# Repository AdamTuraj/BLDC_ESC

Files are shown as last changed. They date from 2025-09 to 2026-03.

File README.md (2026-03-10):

# BLDC ESC

**25A 8.4V Sensored BLDC Motor Driver (DRV8323 Based)**

This ESC was originally designed for my **AT25 project**, but the project was discontinued due to time and budget constraints. The board itself is theoretically still fully functional (I have not physically tested it).

- **Continuous Current:** 25A
- **Peak Current:** 50A
- **Input Voltage:** 8.4V (2S Li-Po)
- **Driver IC:** TI DRV8323
- **Control Mode:** Single PWM mode (simplifies control, avoids heavy math)

## Design Overview

The ESC is built around the **DRV8323** gate driver IC, making use of its 1x PWM control mode for easier firmware integration.

## Renders & Schematics

### 3D Renders

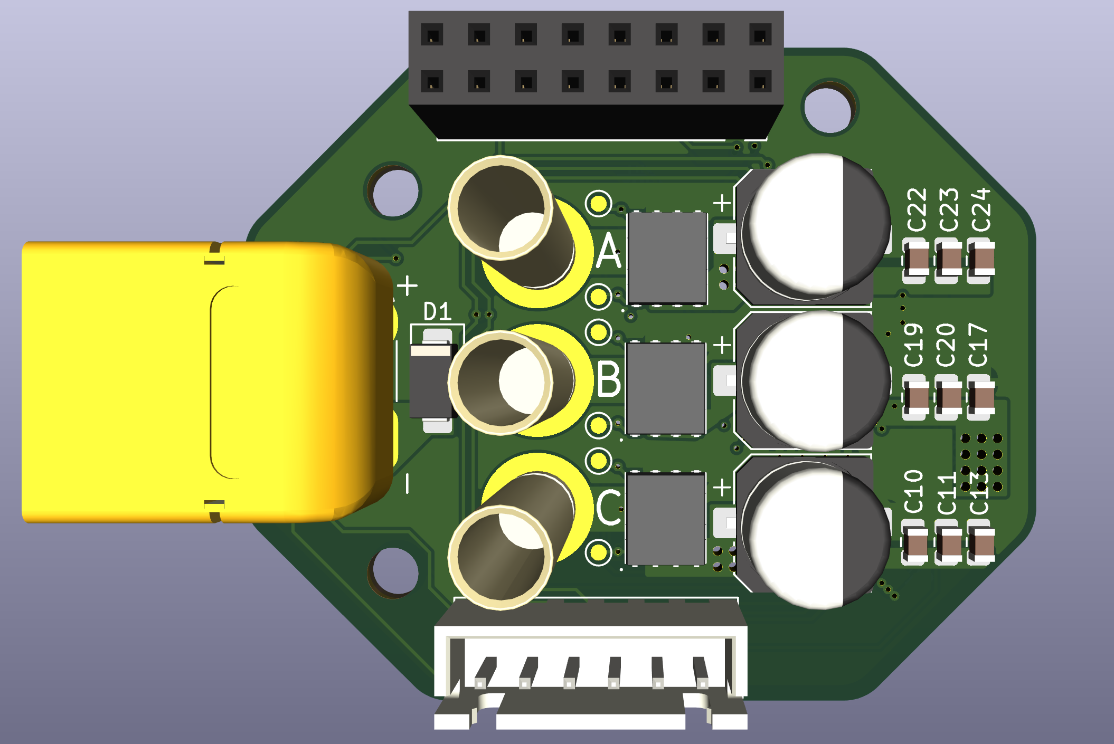
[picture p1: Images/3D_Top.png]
Top 3D view
  
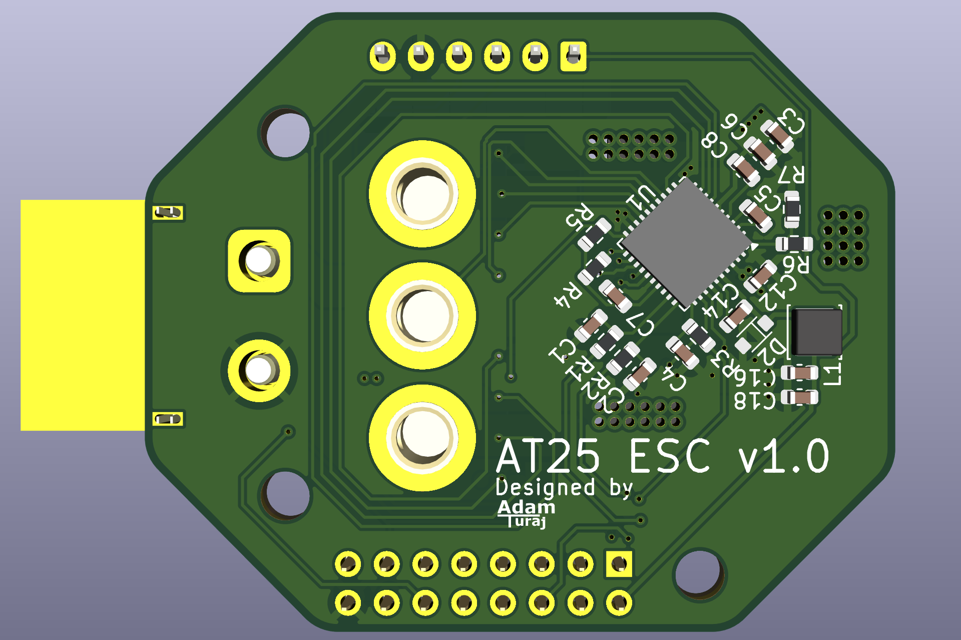
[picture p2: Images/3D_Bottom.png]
Bottom 3D view


### Electrical Schematic

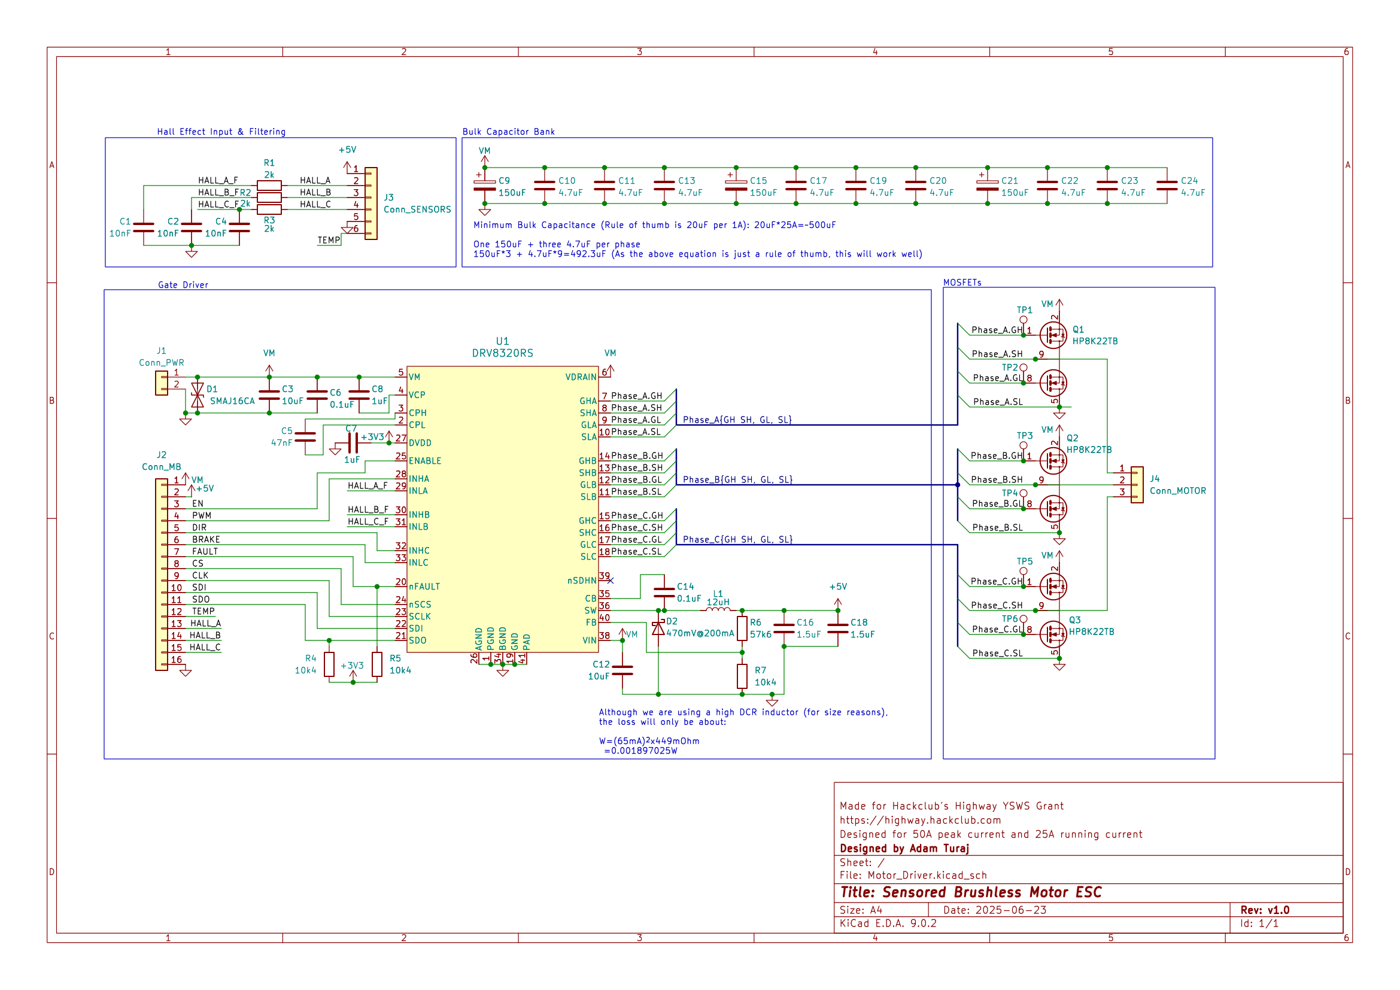
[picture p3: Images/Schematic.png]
Schematic


### PCB Layout (4-Layer Stackup)

- **Top Layer (Signals)**  
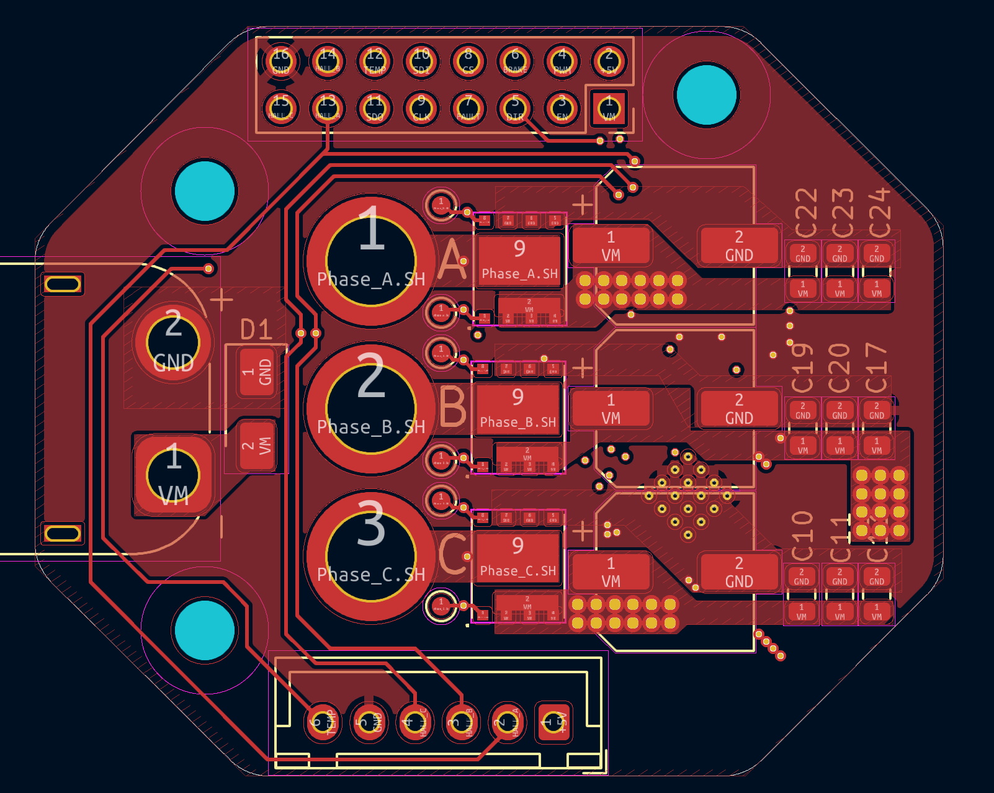
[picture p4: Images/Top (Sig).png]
Top Layer
  

- **Second Layer (Ground Plane)**  
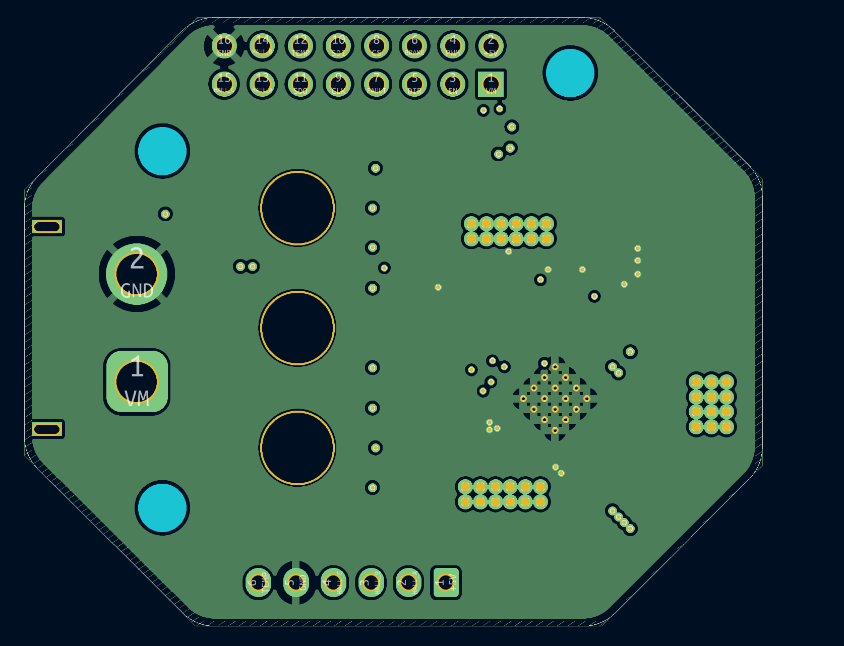
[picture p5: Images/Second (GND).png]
Second Layer
  

- **Third Layer (Power / Signals)**  
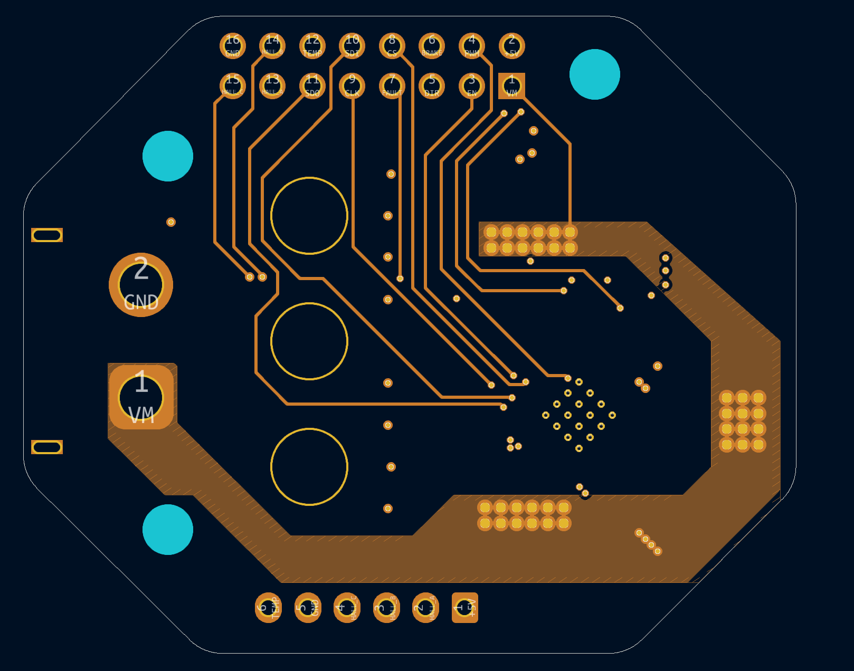
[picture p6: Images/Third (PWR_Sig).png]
Third Layer
  

- **Bottom Layer (Signals)**  
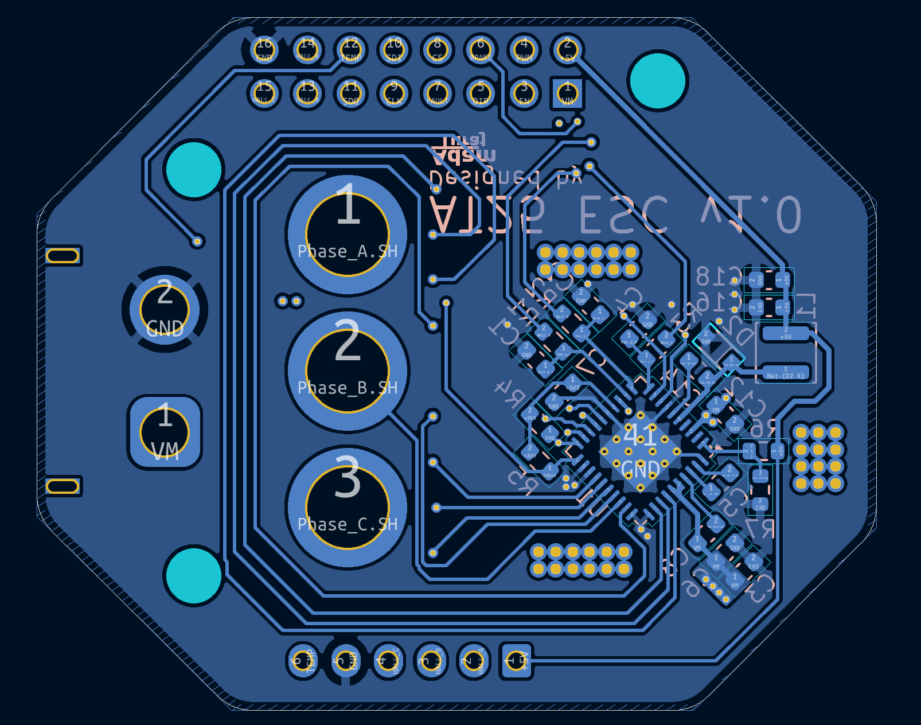
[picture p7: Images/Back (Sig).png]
Bottom Layer


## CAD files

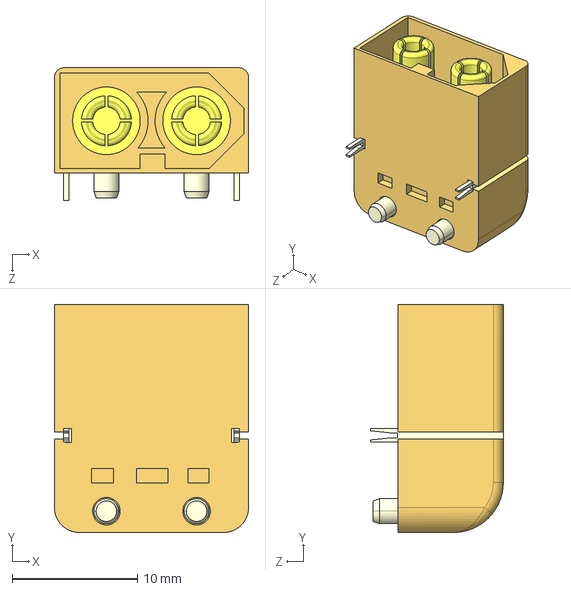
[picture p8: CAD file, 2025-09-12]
STEP/XT60PW-M.STEP
15.5 x 18.2 x 10.6 mm

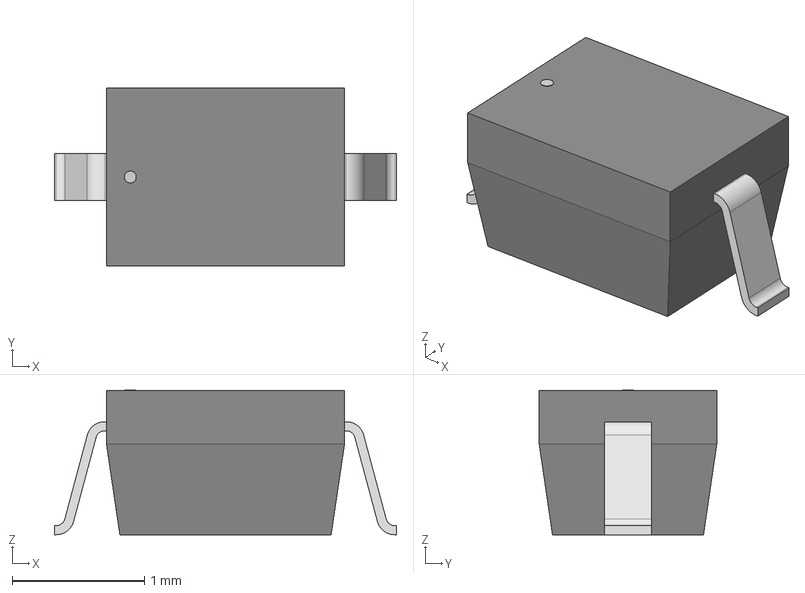
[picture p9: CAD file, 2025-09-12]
STEP/SOD-323_CNS.step
2.59 x 1.35 x 1.09 mm

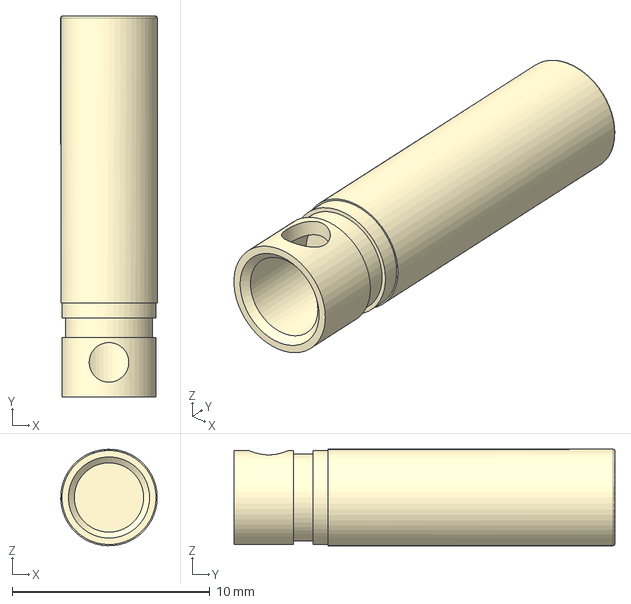
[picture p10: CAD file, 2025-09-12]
STEP/Female_4mm_Bullet_Connector.step
4.88 x 19.2 x 4.88 mm

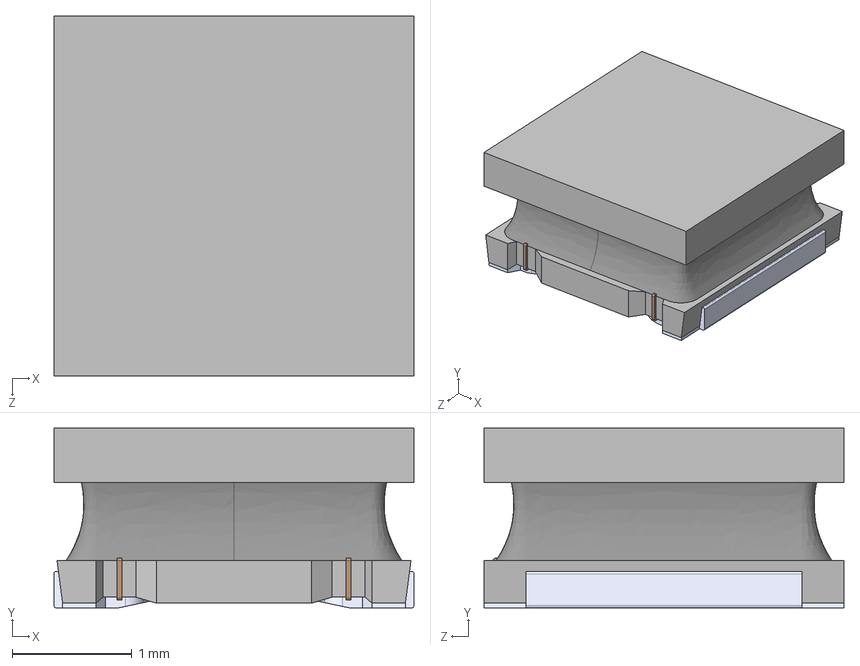
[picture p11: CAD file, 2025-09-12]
STEP/LQH3NPN6R8MMEL.STEP
3.00 x 1.50 x 3.00 mm

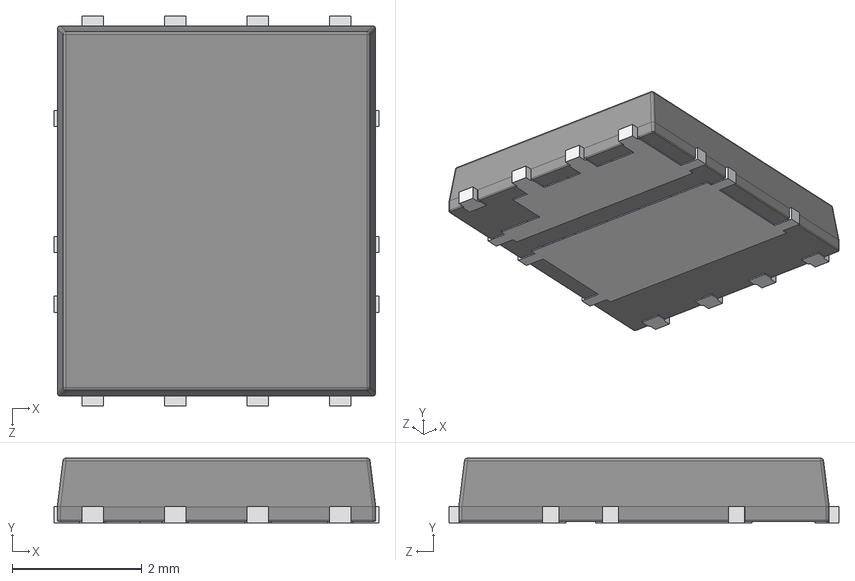
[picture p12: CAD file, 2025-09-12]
STEP/HP8K22TB.stp
5.00 x 1.00 x 6.00 mm

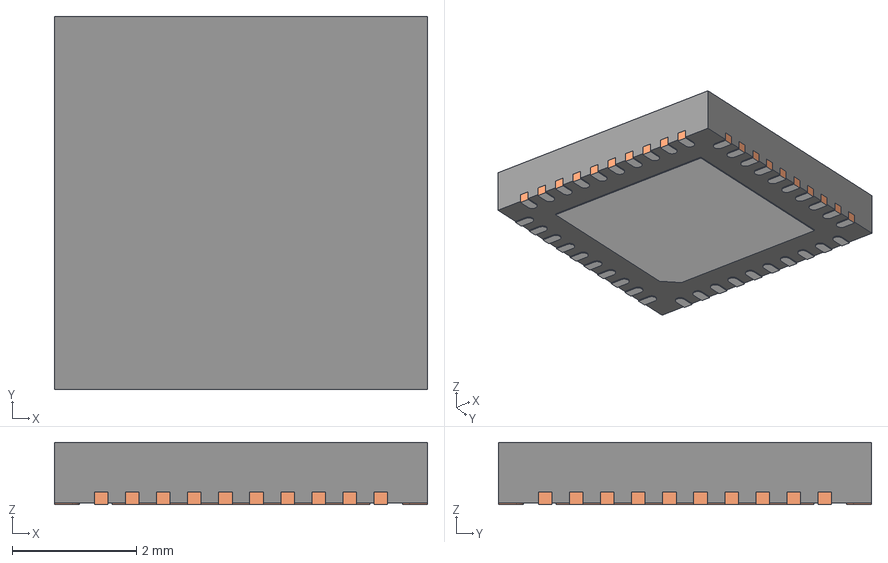
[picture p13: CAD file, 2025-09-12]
STEP/RHA0040B.stp
6.00 x 6.00 x 1.00 mm
BODY-QFN
FRAME-RHA0040B
PIN1-ID

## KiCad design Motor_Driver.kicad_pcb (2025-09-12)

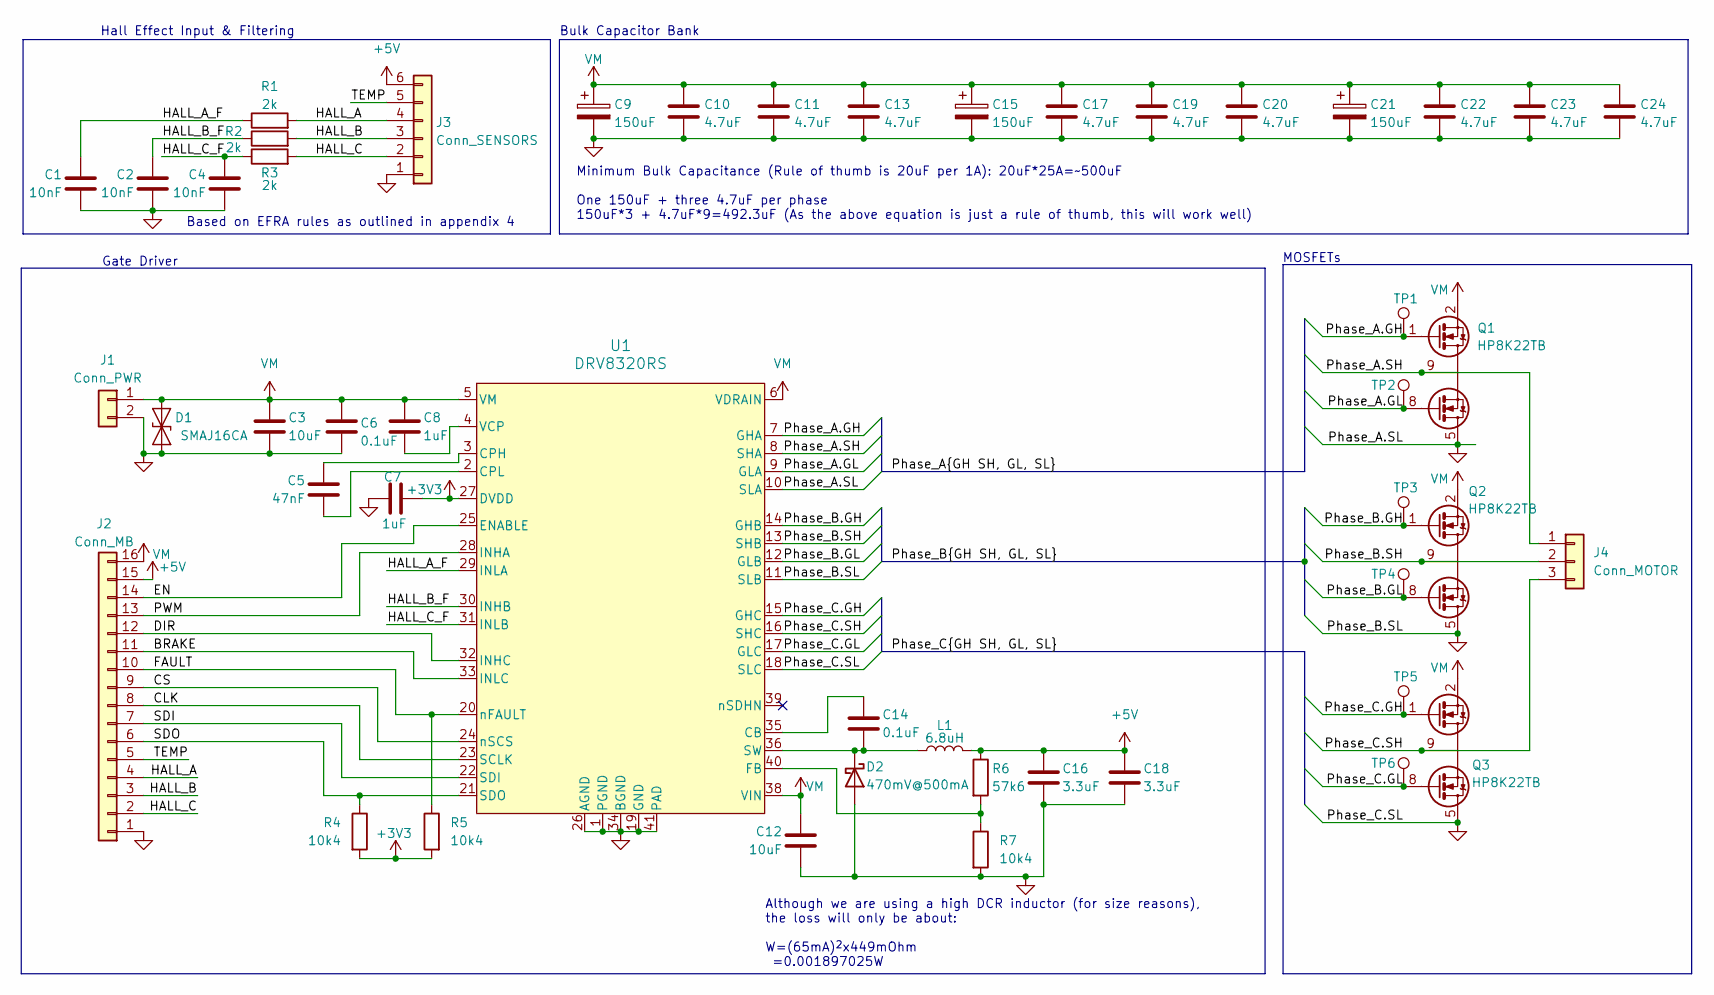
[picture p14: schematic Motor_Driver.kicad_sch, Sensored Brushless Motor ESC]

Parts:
C1, C2, C4: 10nF; C_0603_1608Metric; MPN CL10B103KO8WPNC
C3, C12: 10uF; C_0603_1608Metric; MPN GRM188C81C106MA73D
C5: 47nF; C_0603_1608Metric
C6, C14: 0.1uF; C_0603_1608Metric; MPN CC0603KRX7R7BB104
C7, C8: 1uF; C_0603_1608Metric; MPN CC0603KRX7R7BB105
C9, C15, C21: 150uF; CP_Elec_8x6.9; MPN APXN160ARA151MH70G
C10, C11, C13, C17, C19, C20, C22, C23, C24: 4.7uF; C_0805_2012Metric; MPN CL21B475KOFNNNE
C16, C18: 3.3uF; C_0603_1608Metric; MPN CL10A335KP8NNNC
D1: SMAJ16CA; D_SMA; MPN SMAJ16CA-13-F
D2: 470mV@500mA; D_SOD-323; MPN CMDSH05-4 TR PBFREE
J1: Conn_PWR; AMASS_XT60PW-M_1x02_P7.20mm_Horizontal
J2: Conn_MB; PinSocket_2x08_P2.54mm_Vertical; MPN 10129381-916001BLF
J3: Conn_SENSORS; JST_ZH_B6B-ZR_1x06_P1.50mm_Vertical; MPN B6B-XH-A
J4: Conn_MOTOR; Pin_Bullet_D4.7mm
L1: 6.8uH; L_Vishay_IHLP-1212; MPN LQH3NPN6R8MMEL
Q1, Q2, Q3: HP8K22TB; HP8K24TB; MPN HP8K22TB
R1, R2, R3: 2k; R_0603_1608Metric; MPN RK73B1JTTD202J
R4, R5, R7: 10k4; R_0603_1608Metric; MPN RT0603BRD0710K4L
R6: 57k6; R_0603_1608Metric; MPN RC0603FR-0757K6L
TP1, TP2, TP3, TP4, TP5, TP6: TestPoint; TestPoint_Pad_D1.0mm
U1: DRV8320RS; VQFN-40-1EP_6x6mm_P0.5mm_EP3.5x3.5mm_ThermalVias; MPN DRV8320RSRHAT

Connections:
+3V3: C7.1, R4.2, R5.2, U1.27 (DVDD)
+5V: C16.1, C18.1, J2.15, J3.6, L1.2, R6.1
/BRAKE: J2.11, U1.33 (INLC)
/CLK: J2.8, U1.23 (SCLK)
/CS: J2.9, U1.24 (nSCS)
/DIR: J2.12, U1.32 (INHC)
/EN: J2.14, U1.25 (ENABLE)
/FAULT: J2.10, R5.1, U1.20 (nFAULT)
/HALL_A: J2.4, J3.4, R1.2
/HALL_A_F: C1.1, R1.1, U1.29 (INLA)
/HALL_B: J2.3, J3.3, R2.2
/HALL_B_F: C2.1, R2.1, U1.30 (INHB)
/HALL_C: J2.2, J3.2, R3.2
/HALL_C_F: C4.1, R3.1, U1.31 (INLB)
/PWM: J2.13, U1.28 (INHA)
/Phase_A.GH: Q1.1 (T_{G}), TP1.1, U1.7 (GHA)
/Phase_A.GL: Q1.8 (B_{G}), TP2.1, U1.9 (GLA)
/Phase_A.SH: J4.1, Q1.9 (T_{GR}), U1.8 (SHA)
/Phase_B.GH: Q2.1 (T_{G}), TP3.1, U1.14 (GHB)
/Phase_B.GL: Q2.8 (B_{G}), TP4.1, U1.12 (GLB)
/Phase_B.SH: J4.2, Q2.9 (T_{GR}), U1.13 (SHB)
/Phase_C.GH: Q3.1 (T_{G}), TP5.1, U1.15 (GHC)
/Phase_C.GL: Q3.8 (B_{G}), TP6.1, U1.17 (GLC)
/Phase_C.SH: J4.3, Q3.9 (T_{GR}), U1.16 (SHC)
/SDI: J2.7, U1.22 (SDI)
/SDO: J2.6, R4.1, U1.21 (SDO)
/TEMP: J2.5, J3.5
GND: C1.2, C2.2, C3.2, C4.2, C6.2, C7.2, C9.2, C10.2, C11.2, C12.2, C13.2, C15.2, C16.2, C17.2, C18.2, C19.2, C20.2, C21.2, C22.2, C23.2, C24.2, D1.1 (A1), D2.2 (A), J1.2, J2.1, J3.1, Q1.5 (P_{GND}), Q1.6 (P_{GND}), Q1.7 (P_{GND}), Q2.5 (P_{GND}), Q2.6 (P_{GND}), Q2.7 (P_{GND}), Q3.5 (P_{GND}), Q3.6 (P_{GND}), Q3.7 (P_{GND}), R7.2, U1.1 (PGND), U1.10 (SLA), U1.11 (SLB), U1.18 (SLC), U1.19 (GND), U1.26 (AGND), U1.34 (BGND), U1.41 (PAD)
unnamed: C14.2, D2.1 (K), L1.1, U1.36 (SW)
unnamed: C14.1, U1.35 (CB)
unnamed: C5.1, U1.3 (CPH)
unnamed: C5.2, U1.2 (CPL)
unnamed: R6.2, R7.1, U1.40 (FB)
unnamed: C8.2, U1.4 (VCP)
VM: C3.1, C6.1, C8.1, C9.1, C10.1, C11.1, C12.1, C13.1, C15.1, C17.1, C19.1, C20.1, C21.1, C22.1, C23.1, C24.1, D1.2 (A2), J1.1, J2.16, Q1.2 (V_{IN}), Q1.3 (V_{IN}), Q1.4 (V_{IN}), Q2.2 (V_{IN}), Q2.3 (V_{IN}), Q2.4 (V_{IN}), Q3.2 (V_{IN}), Q3.3 (V_{IN}), Q3.4 (V_{IN}), U1.5 (VM), U1.6 (VDRAIN), U1.38 (VIN)

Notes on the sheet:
MOSFETs
Although we are using a high DCR inductor (for size reasons), the loss will only be about: W=(65mA)^{2}x449mOhm =0.001897025W
Hall Effect Input & Filtering
Based on EFRA rules as outlined in appendix 4
Gate Driver
Minimum Bulk Capacitance (Rule of thumb is 20uF per 1A): 20uF*25A=~500uF One 150uF + three 4.7uF per phase 150uF*3 + 4.7uF*9=492.3uF (As the above equation is just a rule of thumb, this will work well)
Bulk Capacitor Bank

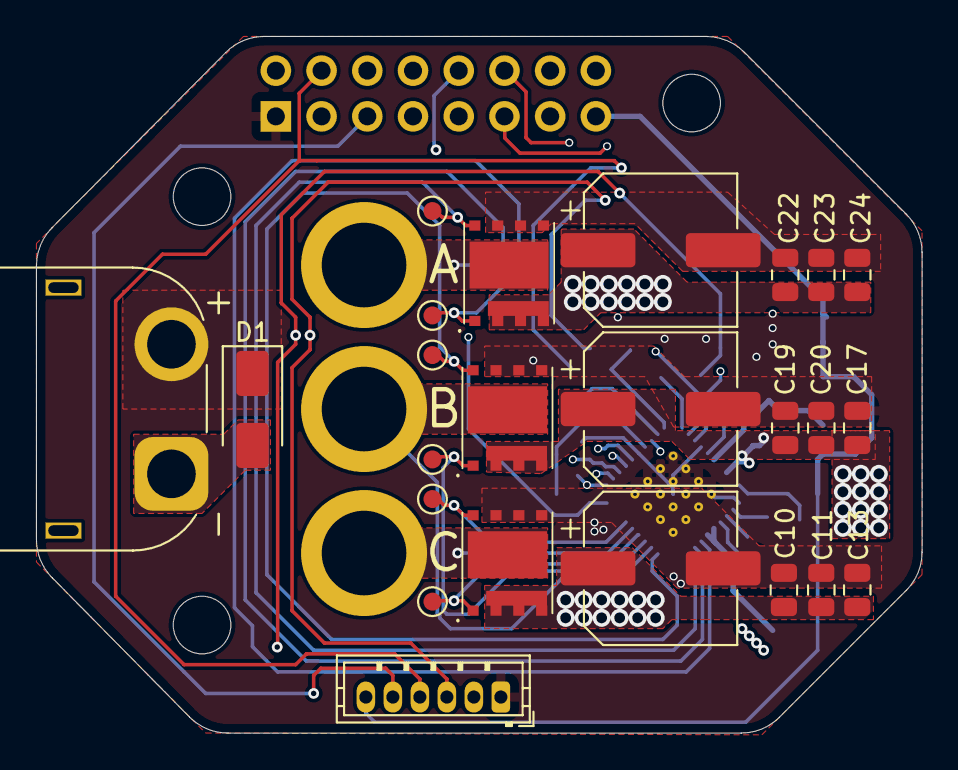
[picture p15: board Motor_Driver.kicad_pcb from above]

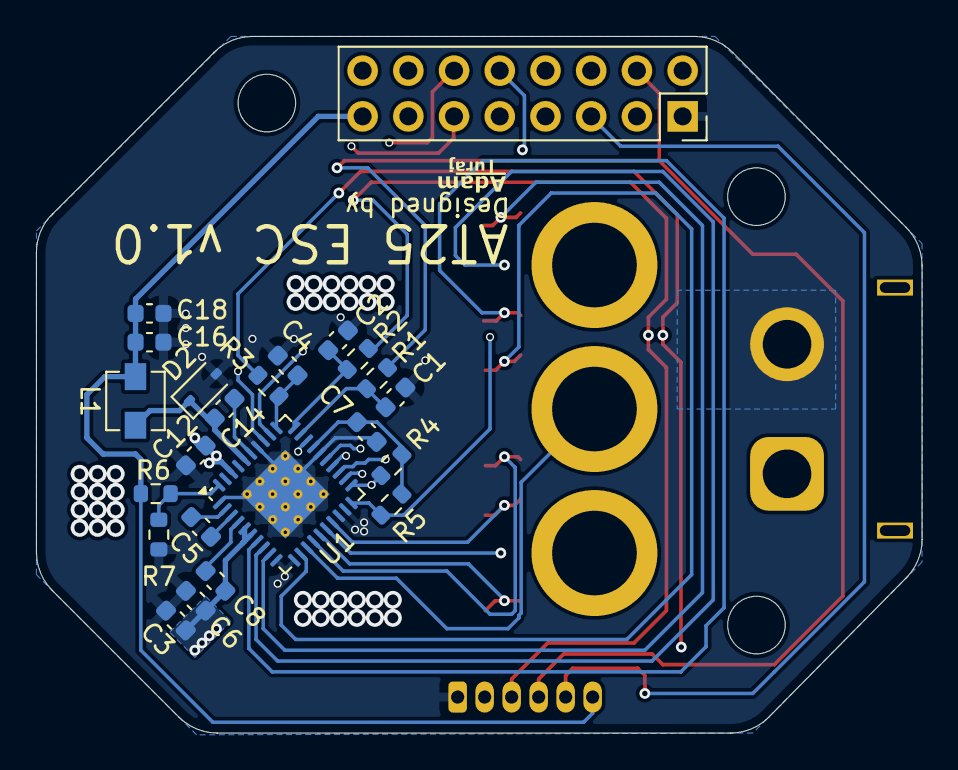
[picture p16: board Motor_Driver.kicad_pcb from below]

Board: 4 copper layers, 49.2 x 38.7 mm, 48 parts (23 on the bottom side), 35 nets.
